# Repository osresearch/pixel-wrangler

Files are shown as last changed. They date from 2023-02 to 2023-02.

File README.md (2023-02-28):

# Pixel Wrangler: HDMI to whatever

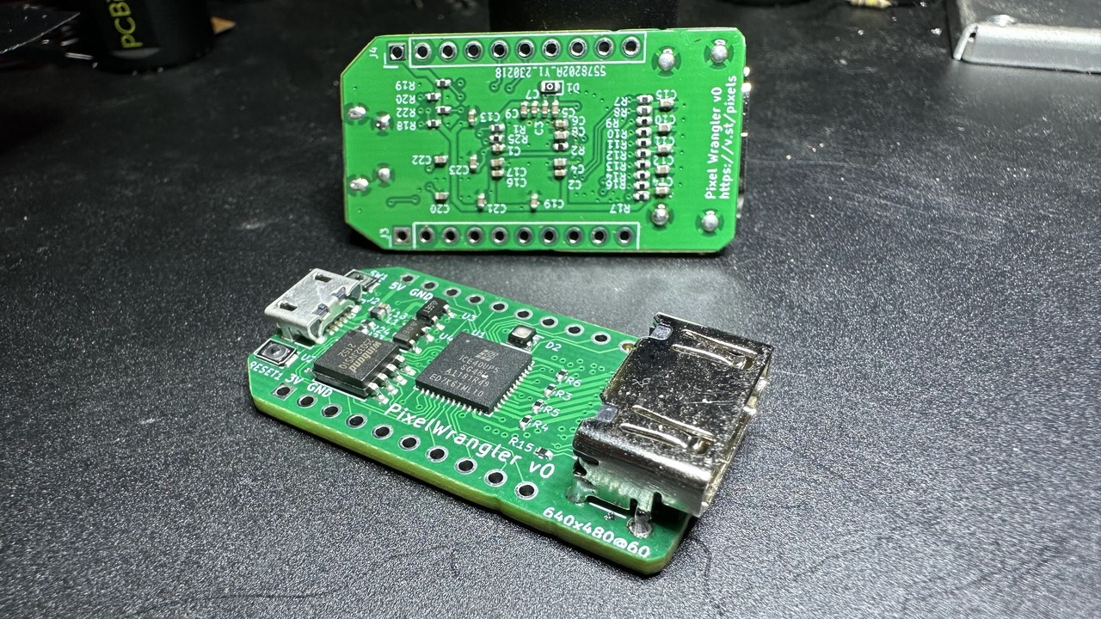
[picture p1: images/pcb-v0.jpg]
Two assembled v0 pixel wrangler boards


The Pixel Wrangler is a tool for converting HDMI video into anything else.
It uses an ice40up5k FPGA to decode the video stream and stores a section
of it in the block RAM, which can then be clocked out of the 16 GPIO pins
in any other format required.

Since the FPGA has total flexibility in how it drives the output pins
it is easily adaptable to different protocols.  Some examples that are possible:

* Classic CRT like the original Mac or Hercules monitors
* LED matrices
* Flip dots
* LED strips (ws2812 or other protocols)
* Lots of servos for "wooden mirrors"

## Does it work?

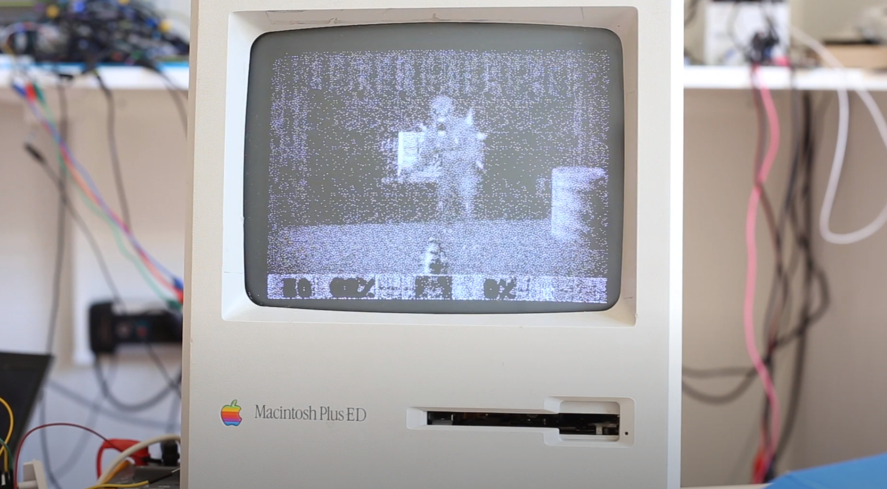
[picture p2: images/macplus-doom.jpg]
Mac Plus "running" Doom


Mostly! The EDID output is good enough to convince Linux to use it as
a normal, if low-resolution, display.  The `mac.bin` monitor mode has
"*live dithering*" to convert the color display into 1-bit, which
works well enough to [play Doom on a 9" Mac Plus](https://www.youtube.com/watch?v=UI3e4YboR_g)!

With `xrandr` it is possible to
have it use a small section of the primary monitor if you don't want a
separate head:

```
xrandr --output HDMI-2 --pos 350x100
```

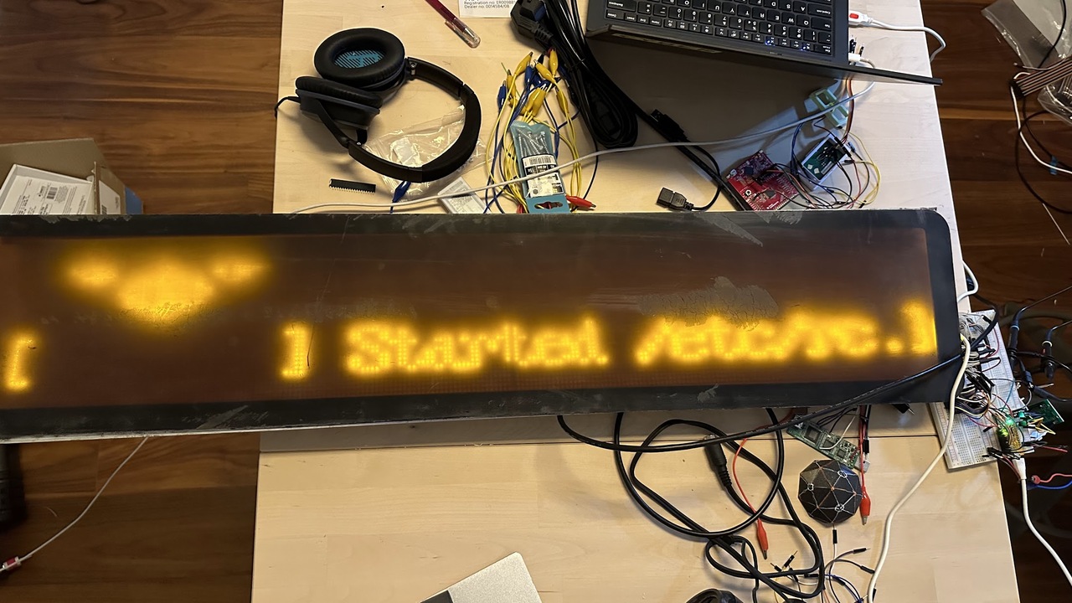
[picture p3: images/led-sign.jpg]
LED sign from a train with the Raspberry Pi boot image


There are some [problems with the v0 boards](https://github.com/osresearch/pixel-wrangler/issues/22),
one of which reqiures a bodge wire on the i2c lines.  The 5v pullups on
the source side of the HDMI i2c also might cause problems in the FPGA,
so the boards need some redesign.

The [TMDS D1 and D2 channels aren't working](https://github.com/osresearch/pixel-wrangler/issues/23),
so right now only the blue data on channel D0 is used.
This might be a clock phase issue or it might be a larger problem;
more research is needed.

The USB Micro is directly connected to the ice40up5k and the flash
can be loaded with [TinyFPGA bootloader `pixelwrangler` branch](https://github.com/osresearch/TinyFPGA-Bootloader/tree/pixelwrangler)
to allow new bit streams to be uploaded into the device.
The [`multiboot.bin`](image/multiboot.bin) is prebuilt and can
be flashed with your SPI flasher of choice and then the `bootmeta.json`
and `boardmeta.json` can be written into the flash security pages.

## PCB design

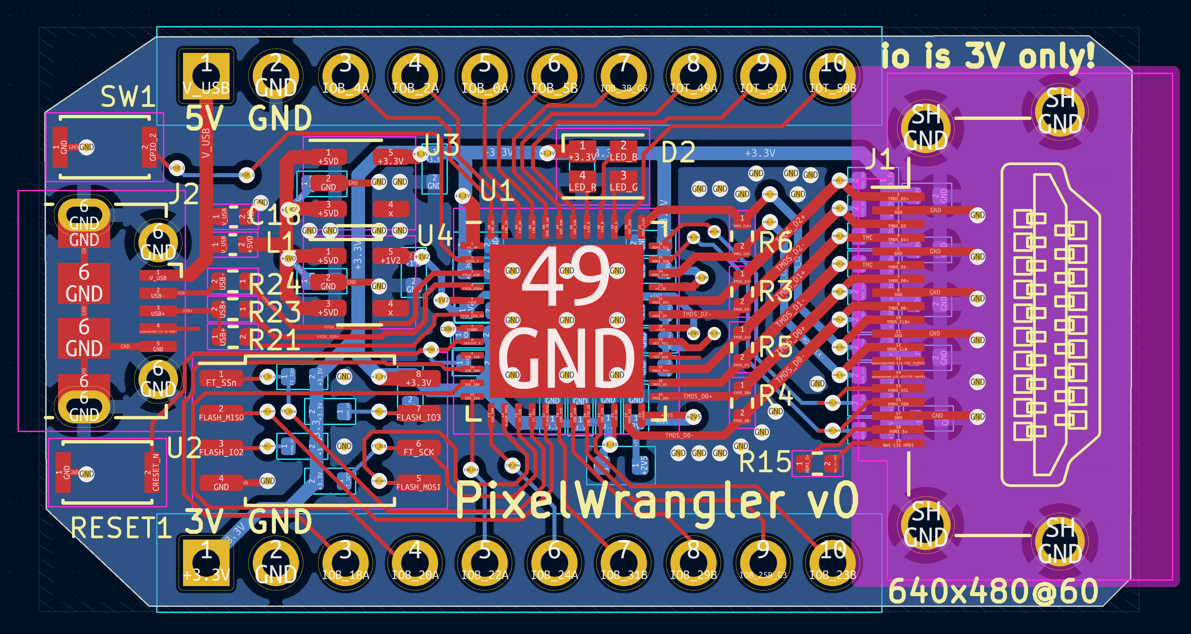
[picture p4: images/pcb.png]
Early PCB layout with air wires


[v0 Schematic](pcb/wrangler_v0.pdf) is based on the [UPduino v3.0 by tinyvision.ai](https://www.tindie.com/products/tinyvision_ai/upduino-v31-low-cost-lattice-ice40-fpga-board/),
heavily modified for this specific application.

The HDMI connector has one differential pair carrying a 25 MHz clock and three differential
pairs running at 250 MHz and carrying 10 bits per pixel.  The clock *must* connect
to the one pin on the ice40up5k that has a LVDS connection to the global clock buffer
so that the pixel clock can be quickly fanned-out to the rest of the logic that uses it.
The three data pairs are routed to the LVDS inputs; D0 and D1 are inverted so that they
don't have to cross on the PCB and must be flipped in the logic.

## Limitations

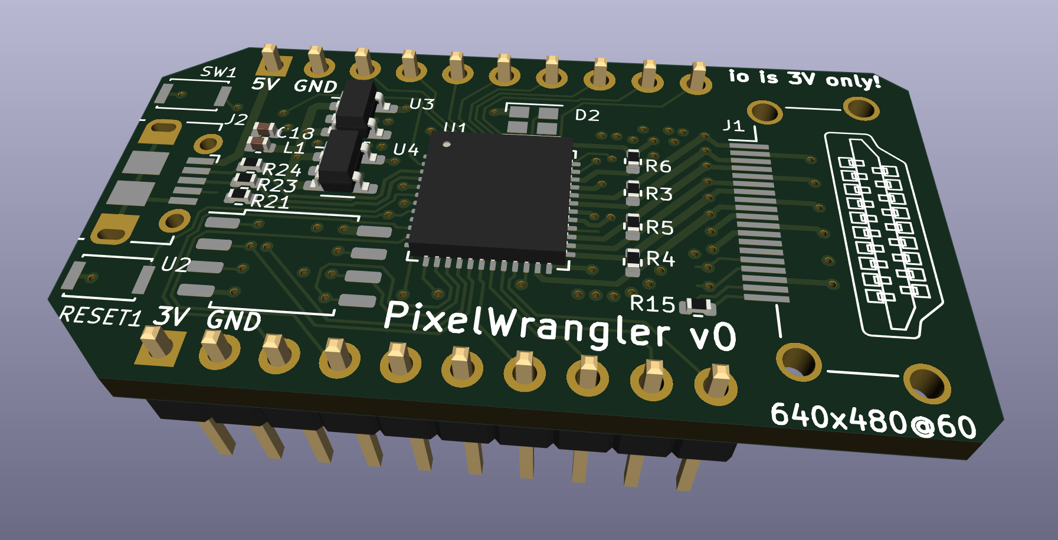
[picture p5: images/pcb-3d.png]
Rendering of the pre-production beta board


* Only "baseline video" is supported
  * 640x480 @ 60Hz
  * 25 MHz maximum pixel clock
* 1 Mib frame buffer memory in the ice40. Resolutions supported are:
  * 1024x1024x1
  * 512x512x4
  * 256x256x16
  * 256x128x24
* 3.3V IO on GPIO pins
* No protection against shorts or overcurrent. Be careful!
* Boot loader requires button press to reset
* There isn't any USB support in the bit stream tree yet.

## Dithering

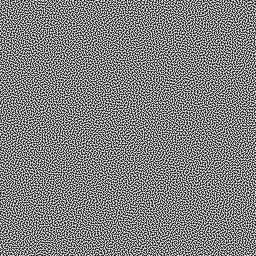
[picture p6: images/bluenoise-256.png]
256x256 Blue Noise matrix


Dithering uses Ordered Blue Noise Dithering. Pattern is from [gao-duan](https://github.com/gao-duan/BlueNoise) (MIT Licensed).
Currently limited to a 64x64 size pattern; ideally a larger RGB
image could be loaded from the SPI flash at boot time, which would
allow three channel dithering without repeating across the screen.

## Todo

* [X] Finish board design -- ordered!
* [X] EDID ROM and i2c interface
* [X] DDR on input for ~~high-res~~ inputs
* [X] Classic Mac mode -- working!
* [ ] Fix TMDS channel D1 and D2 decoding
* [ ] Documentation on writing new interfaces
* [ ] LED strip mode
* [ ] Load larger dithering pattern from flash?

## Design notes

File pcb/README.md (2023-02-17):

This is derived from the UPduino v3 board design by tinyvision-ai-inc:
https://github.com/tinyvision-ai-inc/UPduino-v3.0

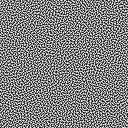
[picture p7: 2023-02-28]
images/bluenoise-128.png

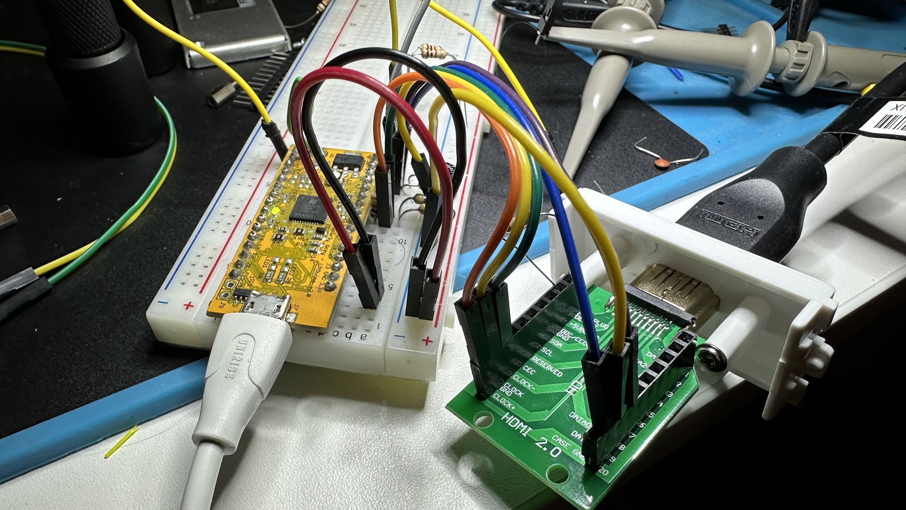
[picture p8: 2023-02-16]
images/breadboard.jpg

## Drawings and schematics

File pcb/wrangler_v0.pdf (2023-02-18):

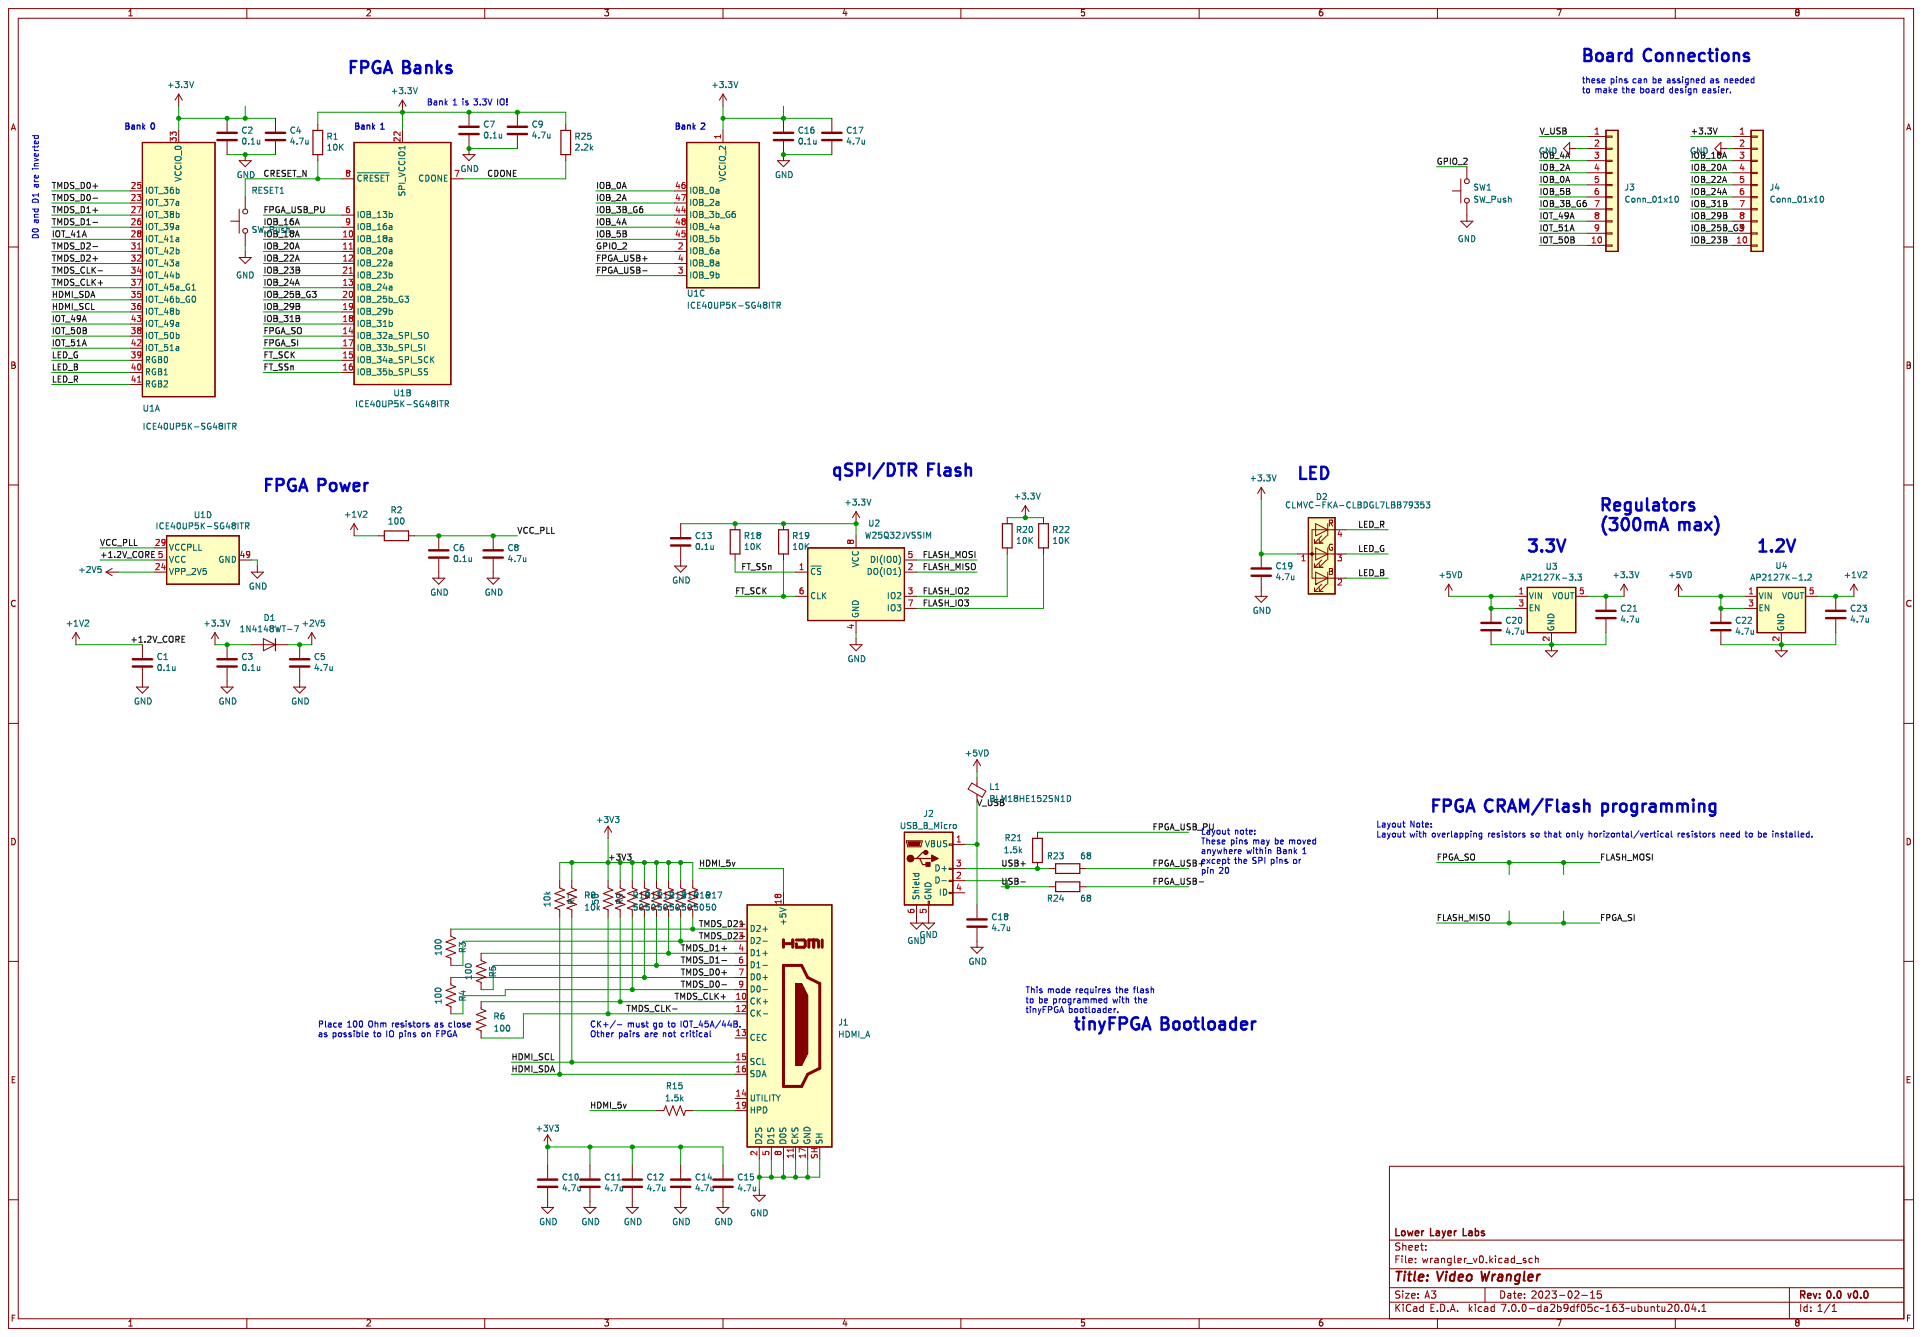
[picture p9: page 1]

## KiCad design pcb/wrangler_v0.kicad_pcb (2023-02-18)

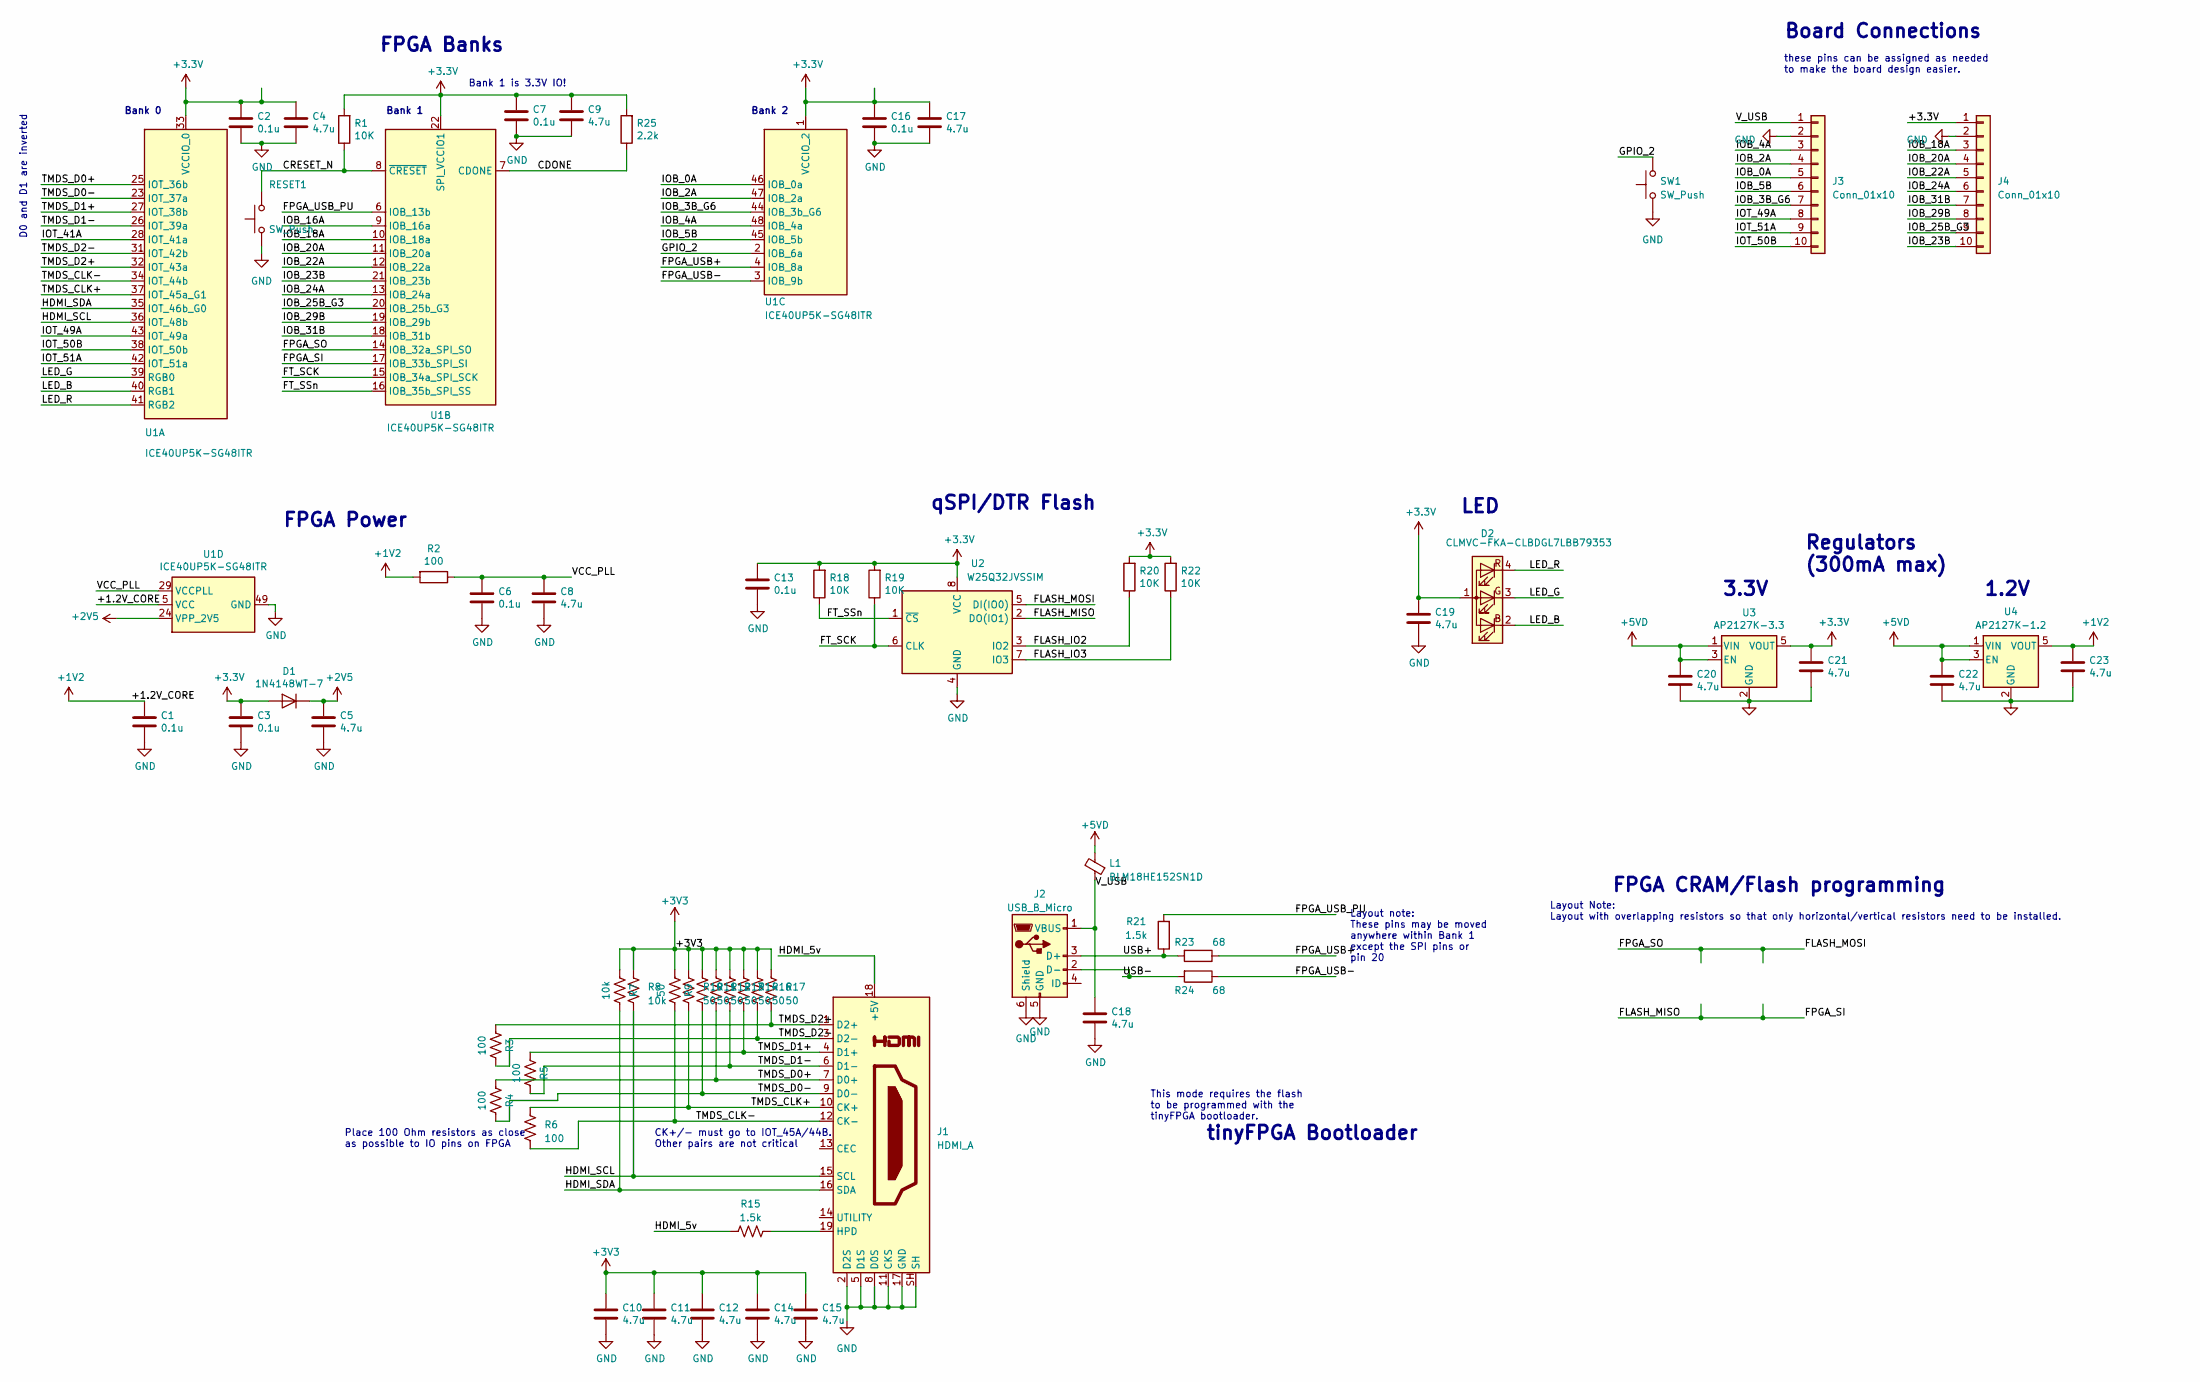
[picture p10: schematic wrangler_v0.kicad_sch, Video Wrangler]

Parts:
C1, C3, C6, C7, C13, C16: 0.1u; C_0402_1005Metric
C2: 0.1u; C_0402_1005Metric; MPN C1005X5R0J104K050BA
C4, C5, C8, C9, C10, C11, C12, C14, C15, C17, C18, C19, C20, C21, C22, C23: 4.7u; C_0402_1005Metric
D1: 1N4148WT-7; D_SOD-523
D2: CLMVC-FKA-CLBDGL7LBB79353; LED_Cree-PLCC4_2x2mm_CW
J1: HDMI_A; HDMI_A_Amphenol_10029449-x01xLF_Horizontal
J2: USB_B_Micro; USB_Micro-B_Molex-105017-0001
J3, J4: Conn_01x10; PinHeader_1x10_P2.54mm_Vertical
L1: BLM18HE152SN1D; C_0402_1005Metric
R1, R18, R19, R20, R22: 10K; R_0402_1005Metric
R2, R3, R4, R5, R6: 100; R_0402_1005Metric
R7, R8: 10k; R_0402_1005Metric
R9, R10, R11, R12, R13, R14, R16, R17: 50; R_0402_1005Metric
R15, R21: 1.5k; R_0402_1005Metric
R23, R24: 68; R_0402_1005Metric
R25: 2.2k; R_0402_1005Metric
RESET1: SW_Push; SW_SPST_CK_KXT3
SW1: SW_Push; SW_SPST_CK_KXT3
U1: ICE40UP5K-SG48ITR; QFN-48-1EP_7x7mm_P0.5mm_EP5.6x5.6mm
U2: W25Q32JVSSIM; SOIC-8_5.23x5.23mm_P1.27mm
U3: AP2127K-3.3; SOT-23-5
U4: AP2127K-1.2; SOT-23-5

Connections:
+1V2: C1.1, C23.1, R2.2, U1.5 (VCC), U1.30 (VCC), U4.5 (VOUT)
+2V5: C5.1, D1.1 (K), U1.24 (VPP_2V5)
+5VD: C20.1, C22.1, L1.2, U3.1 (VIN), U3.3 (EN), U4.1 (VIN), U4.3 (EN)
/CDONE: R25.1, U1.7 (CDONE)
/CRESET_N: R1.1, RESET1.2, U1.8 (~CRESET)
/FLASH_IO2: R20.1, U2.3 (IO2)
/FLASH_IO3: R22.1, U2.7 (IO3)
/FLASH_MISO: U1.17 (IOB_33b_SPI_SI), U2.2 (DO(IO1))
/FLASH_MOSI: U1.14 (IOB_32a_SPI_SO), U2.5 (DI(IO0))
/FPGA_USB+: R23.1, U1.4 (IOB_8a)
/FPGA_USB-: R24.1, U1.3 (IOB_9b)
/FPGA_USB_PU: R21.2, U1.6 (IOB_13b)
/FT_SCK: R19.1, U1.15 (IOB_34a_SPI_SCK), U2.6 (CLK)
/FT_SSn: R18.1, U1.16 (IOB_35b_SPI_SS), U2.1 (~CS)
/GPIO_2: SW1.2, U1.2 (IOB_6a)
/HDMI_5v: J1.18 (+5V), R15.1
/HDMI_SCL: J1.15 (SCL), R8.2, U1.36 (IOT_48b)
/HDMI_SDA: J1.16 (SDA), R7.2, U1.35 (IOT_46b_G0)
/IOB_0A: J3.5, U1.46 (IOB_0a)
/IOB_2A: J3.4, U1.47 (IOB_2a)
/IOB_3B_G6: J3.7, U1.44 (IOB_3b_G6)
/IOB_4A: J3.3, U1.48 (IOB_4a)
/IOB_5B: J3.6, U1.45 (IOB_5b)
/IOB_16A: U1.9 (IOB_16a)
/IOB_18A: J4.3, U1.10 (IOB_18a)
/IOB_20A: J4.4, U1.11 (IOB_20a)
/IOB_22A: J4.5, U1.12 (IOB_22a)
/IOB_23B: J4.10, U1.21 (IOB_23b)
/IOB_24A: J4.6, U1.13 (IOB_24a)
/IOB_25B_G3: J4.9, U1.20 (IOB_25b_G3)
/IOB_29B: J4.8, U1.19 (IOB_29b)
/IOB_31B: J4.7, U1.18 (IOB_31b)
/IOT_41A: U1.28 (IOT_41a)
/IOT_49A: J3.8, U1.43 (IOT_49a)
/IOT_50B: J3.10, U1.38 (IOT_50b)
/IOT_51A: J3.9, U1.42 (IOT_51a)
/LED_B: D2.2 (RK), U1.40 (RGB1)
/LED_G: D2.3 (GK), U1.39 (RGB0)
/LED_R: D2.4 (BK), U1.41 (RGB2)
/TMDS_CLK+: J1.10 (CK+), R6.1, R10.2, U1.37 (IOT_45a_G1)
/TMDS_CLK-: J1.12 (CK-), R6.2, R9.2, U1.34 (IOT_44b)
/TMDS_D0+: J1.7 (D0+), R4.1, R12.2, U1.25 (IOT_36b)
/TMDS_D0-: J1.9 (D0-), R4.2, R11.2, U1.23 (IOT_37a)
/TMDS_D1+: J1.4 (D1+), R5.1, R14.2, U1.27 (IOT_38b)
/TMDS_D1-: J1.6 (D1-), R5.2, R13.2, U1.26 (IOT_39a)
/TMDS_D2+: J1.1 (D2+), R3.1, R17.2, U1.32 (IOT_43a)
/TMDS_D2-: J1.3 (D2-), R3.2, R16.2, U1.31 (IOT_42b)
/USB+: J2.3 (D+), R21.1, R23.2
/USB-: J2.2 (D-), R24.2
/VCC_PLL: C6.1, C8.1, R2.1, U1.29 (VCCPLL)
/V_USB: C18.1, J2.1 (VBUS), J3.1, L1.1
GND: C1.2, C2.2, C3.2, C4.2, C5.2, C6.2, C7.2, C8.2, C9.2, C10.2, C11.2, C12.2, C13.2, C14.2, C15.2, C16.2, C17.2, C18.2, C19.2, C20.2, C21.2, C22.2, C23.2, J1.2 (D2S), J1.5 (D1S), J1.8 (D0S), J1.11 (CKS), J1.17 (GND), J1.SH, J2.5 (GND), J2.6 (Shield), J3.2, J4.2, RESET1.1, SW1.1, U1.49 (GND), U2.4 (GND), U3.2 (GND), U4.2 (GND)
unnamed: J1.19 (HPD), R15.2

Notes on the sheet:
Bank 1
Bank 1 is 3.3V IO!
Layout note: These pins may be moved anywhere within Bank 1 except the SPI pins or pin 20
tinyFPGA Bootloader
LED
FPGA Power
This mode requires the flash to be programmed with the tinyFPGA bootloader.
CK+/- must go to IOT_45A/44B. Other pairs are not critical
Layout Note: Layout with overlapping resistors so that only horizontal/vertical resistors need to be installed.
3.3V
D0 and D1 are inverted
Place 100 Ohm resistors as close as possible to IO pins on FPGA
Bank 0
Board Connections
1.2V
Bank 2
qSPI/DTR Flash
FPGA Banks
Regulators (300mA max)
these pins can be assigned as needed to make the board design easier.
FPGA CRAM/Flash programming

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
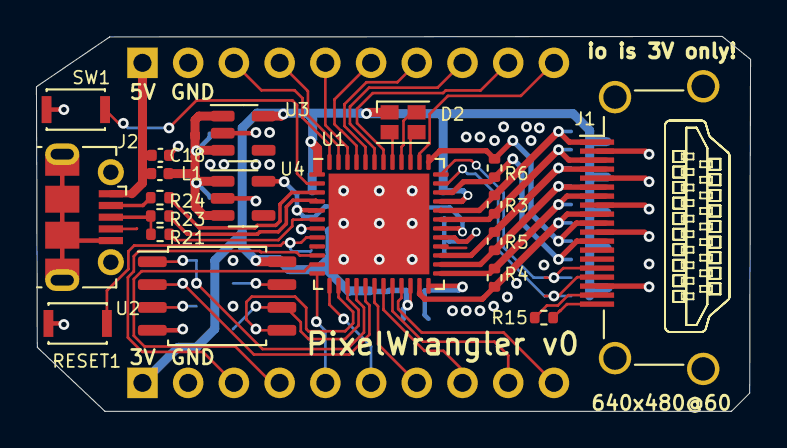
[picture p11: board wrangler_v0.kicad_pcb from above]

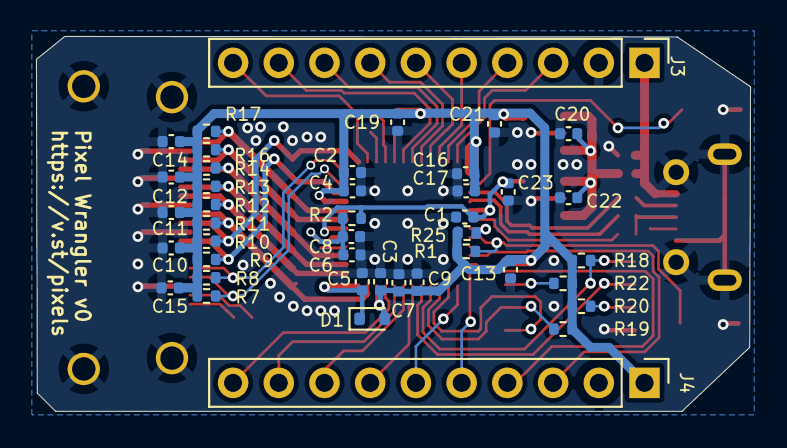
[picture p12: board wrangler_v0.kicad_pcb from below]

Board: 4 copper layers, 39.7 x 20.8 mm, 61 parts (42 on the bottom side), 52 nets.

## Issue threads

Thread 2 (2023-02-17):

CDONE needs to be tied high and SPI flash boot mode

osresearch, 2023-02-17:
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

According to the ice40 programming guide `CDONE` has to be tied high with a 2.7K resistor, and `SPI_SS_B` should have a 10K pullup.

osresearch, 2023-02-17:
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

* FPGA is in SPI controller mode
* `SPI_SO` is output from the FPGA. connects to flash MOSI
* `SPI_SI` is input to the FPGA, connects to flash MISO
* `SPI_SS_B` has 10k pullup

osresearch, 2023-02-18:
Fixed in v0 tag prior to ordering.

Closed 2023-02-18.

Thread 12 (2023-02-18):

usb bootloader

osresearch, 2023-02-18:
The boards don't have a FTDI chip, so it is necessary to have a bootloader.  TinyFPGA has one, FOMU has a DFU based one.

osresearch, 2023-02-18:
Hopefully it works without a crystal.  if not we can just route normal serial over the USB micro in a total non-standard sort of connector.

osresearch, 2023-03-01:
tinyfpga bootloader works as part of v0 fixes merge.  pre-built binary checked in, pull request opened for tinyfpga tree.

Closed 2023-03-01.

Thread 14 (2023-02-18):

tmds decoder needs invert option

osresearch, 2023-02-18:
Since the v0 board inverts some of the TMDS pairs to avoid crossings of traces on the PCB, the `tmds_shiftregister` or `tmds_decoder` needs an invert parameter.

osresearch, 2023-03-01:
Done as part of v0 fixes merge

Closed 2023-03-01.

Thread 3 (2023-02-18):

EDID emulator

osresearch, 2023-02-18:
The EDID format is awful, but we need to support it anyway...

Adafruit has some example EDID roms that do 800x600 and other formats; maybe we can hack one of those to implement the 640x480@60 timings.

ladyada, 2023-02-18:
i have lost significant life to EDID hacking - just FYI...some OS's 'cache' EDIDs: linux does, windows doesn't seem to. so if you're wondering why it doesn't reload, thats why. there's lots of EDID editors/generateors/extractors tools used in the AV world that are downloadable for free (google for edid editor)

osresearch, 2023-02-18:
Thanks for the advice!

I'm surprised there isn't any online editor, only only decoders.  I can't get the deltacast one to run under wine, so i'll need to spinup a real windows vm to try it out.

osresearch, 2023-02-19:
Hacking in a soft i2c core since I can't figure out Lattice's i2c device and it seems that icestorm devs don't recommend it anyway...

```
[3555446.841541] i915 0000:00:02.0: HDMI-A-2: EDID is invalid:
[3555446.841543]        [00] BAD  00 ff ff ff ff ff ff 00 5a 74 01 00 57 04 00 00
[3555446.841544]        [00] BAD  0a 21 01 04 a2 00 00 78 00 00 00 00 00 00 00 00
[3555446.841544]        [00] BAD  00 00 00 20 00 00 31 40 01 00 01 00 01 00 01 00
[3555446.841545]        [00] BAD  01 00 01 00 01 00 d5 09 80 a0 20 c1 ff ff ff ff
[3555446.841545]        [00] BAD  ff ff ff ff ff ff ff ff ff ff ff ff ff ff ff ff
[3555446.841545]        [00] BAD  ff ff ff ff ff ff ff ff ff ff ff ff ff ff ff ff
[3555446.841546]        [00] BAD  ff ff ff ff ff ff ff ff ff ff ff ff ff ff ff ff
[3555446.841546]        [00] BAD  ff ff ff ff ff ff ff ff ff ff ff ff ff ff ff ff
[3555451.384838] i2c i2c-1: sendbytes: NAK bailout.
[3555455.772344] i2c i2c-1: sendbytes: NAK bailout.
```

osresearch, 2023-02-19:
for future reference, i2c eeprom address is 0x50.  getting closer!
```
sudo get-edid -i -b 1 | parse-edid
1
This is read-edid version 3.0.2. Prepare for some fun.
Attempting to use i2c interface
Only trying 1 as per your request.
256-byte EDID successfully retrieved from i2c bus 1
Looks like i2c was successful. Have a good day.
WARNING: Checksum failed
Trying to continue...
Section "Monitor"
	Identifier "Pixe���angler"
	ModelName "Pixe���angler"
	VendorName "VST"
	# Monitor Manufactured week 10 of 2023
	# EDID version 1.255
	# Digital Display
	# Display Physical Size not given. Normal for projectors.
	Gamma 2.20
	Option "DPMS" "false"
	#Not giving standard mode: 640x480, 60Hz
	#Not giving standard mode: 256x160, 60Hz
	#Not giving standard mode: 256x160, 60Hz
	#Not giving standard mode: 256x160, 60Hz
	#Not giving standard mode: 256x160, 60Hz
	#Not giving standard mode: 256x160, 60Hz
	#Not giving standard mode: 256x160, 60Hz
	#Not giving standard mode: 256x160, 60Hz
EndSection
```

osresearch, 2023-02-19:
oh no, it looks like to be HDMI compliant the i2c lines are supposed to be pulled up to 5V, not 3.3V.  the ice40up5k isn't 5v tolerant, so that would require a bidirectional level shifter on the SDA line (the SCL is input only).  this would complicate things.

osresearch, 2023-02-20:
Hurrah! the i2c device now properly implements the repeated START state and delivers an error free EDID, although x isn't swithcing to it for some reason.

https://github.com/osresearch/pixel-wrangler/commit/0d43c9e86c644c38e9c9a46d856a12ce9686b799

osresearch, 2023-02-20:
Linux (x86) can be forced to use the HDMI even though it doesn't like the EDID:

```
echo on-digital | sudo tee /sys/class/drm/card0-HDMI-A-2/status
xrandr --output HDMI-2 --mode 640x480
```

Hot plug isn't doing the right thing, although if you mess with the pullup resistor it can cause the kernel to decide that there is a drm interrupt storm.

The adafruit 800x480 EDID almost works, although we can't handled the 32 MHz pixel clock yet.

osresearch, 2023-02-20:
I think the EDID emulation works well enough now:
```
sudo get-edid  -b 1 | parse-edid
1
This is read-edid version 3.0.2. Prepare for some fun.
Attempting to use i2c interface
Only trying 1 as per your request.
256-byte EDID successfully retrieved from i2c bus 1
Looks like i2c was successful. Have a good day.
Checksum Correct

Section "Monitor"
	Identifier "PixelWrangler"
	ModelName "PixelWrangler"
	VendorName "PXL"
	# Monitor Model Year: 2023
	# EDID version 1.4
	# Digital Display
	DisplaySize 640 480
	Gamma 2.20
	Option "DPMS" "false"
	Modeline 	"Mode 0" 25.17 640 656 752 800 480 490 492 525 -hsync -vsync
EndSection
```

The problem appears to be with hotplug or with X rejecting the 640x480 display parameters?  Let's move that to a new issue.

Closed 2023-02-20.

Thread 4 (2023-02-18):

DDR phase tracking is not good

osresearch, 2023-02-18:
Sometimes it doesn't seem to lock on, ever?

Maybe needs to track both positive and negative possibilities?

Phase counter needs to go from 0 to 5, not up to 10.

Closed 2023-03-23.

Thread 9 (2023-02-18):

LED is too bright

osresearch, 2023-02-18:
the ice40 rgb driver has current control; turn it down!

osresearch, 2023-03-01:
rgb driver and pwm with exponential scaling merged as part of v0

Closed 2023-03-01.

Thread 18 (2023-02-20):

tmds sync requires reset to resync

osresearch, 2023-02-20:
I think #6 is fixed with the DDR mode, but there is still a problem that decoder doesn't resync with the stream after a hotplug. it requires the full fpga to reset to come back to working.

osresearch, 2023-02-20:
Adding an async `hdmi_reset` signal seems to have worked.  the blue LED shows when it is being asserted, and it is very bright....

Closed 2023-02-20.

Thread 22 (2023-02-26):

v0 board issues

osresearch, 2023-02-26:
* [ ] L1 is too close to cap on the top
* [ ] Reset and SW1 should be brought to the headers
* [ ] Two IOs are not routed out
* [ ] USB footprint isn't quite right
* [ ] USB resistors are on the top; move to bottom?
* [ ] Add a clock?
* [ ] Reduce size of paste window under ice40
* [ ] Make sure to order ENIG plating!
* [ ] 1.2mm thick PCB
* [ ] Smaller stencil size

cibomahto, 2023-02-26:
My suggestions:
* Change button type to 'TS-1185-C-A-A': https://www.lcsc.com/product-detail/Others_XKB-TS-1185-C-A-A_C318896.html (slightly larger but more robust/very common)
* Change USB type to 'MICRO XNJ ZB' https://www.lcsc.com/product-detail/USB-Connectors_SHOU-HAN-MICRO-XNJ-ZB_C668587.html (this works with the current footprint?)
* Suggest 2520 oscillator package size, for example: https://www.lcsc.com/product-detail/Oscillators_Yangxing-Tech-OT252012MJBA4SL_C669073.html
* Leave USB resistors on top side (keep USB lines on a single plane to avoid discontinuities)
* Consider if the other end of the I2C pins are being pulled up to 5V, which would make a voltage conflict.

osresearch, 2023-02-26:
Thanks for the suggestions!

Software patches are being developed in https://github.com/osresearch/pixel-wrangler/tree/v0-fixes

osresearch, 2023-02-27:
For the i2c pullups, perhaps using a device-side version of the [TPD12S016 "HDMI Companion chip"](https://nl.mouser.com/ProductDetail/Texas-Instruments/TPD12S016RKTR) would be a good idea.  It adds ESD protection on all eight differential pairs, i2c level shifting, etc.

osresearch, 2023-02-27:
After soldering a jumper from the SDA pullup resistor to GPIO 0 7, the i2c works and the laptop negotiates with the display.  All three channel decode works.  Green is inverted on schematic, but doesn't get inverted in the verilog?  Something seems wrong with that.

osresearch, 2023-12-07:
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

I forgot to check all the replies to this issue and forgot to change the switch or USB footprints.  I did fix the i2c connections and moved everything to one side for easier manufacturing.

Aisler is doing the prototype and they only have thick PCBs.

osresearch, 2024-02-10:
And some v2 board issues:

The biggest:

* The v2 boards won't sync up their PLL, so they never get the video (maybe the througholes are a bad idea)
* Maybe this is a bad idea and it should just use an HDMI chip

And some other ones:

* Not having an oscillator means that free running video outputs have some shimmer (on v0 and v2).
* Buttons are still too hard to press
* USB micro rips off sometimes
* Initial program load is a problem; have to figure out how to make it work on populated boards
* Boot loader doesn't time out and start video automatically
* Boot loader metadata isn't populated correctly

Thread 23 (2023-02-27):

TMDS D1 and D2 phases

osresearch, 2023-02-27:
Are we getting 0-255 or 16-235?

osresearch, 2023-02-27:
Blue gradient:
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

Red gradient:
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

Green gradient:
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

It's not a full RGB issue, it appears to be a TMDS phase issue.  The blue channel on D0 can synchronize on the vsync with all of its 01 transitions, but the D1 and D2 don't have that option. The 8b10b encoding for 0x00 and 0xFF have very few transitions, so out of phase means that the decoder mostly gets ok data for full on and full off.  But if D1 and D2 are on different phases, they will have garbage.

osresearch, 2023-02-28:
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

the control bits are the same on each channel:

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

and the patterns are
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

osresearch, 2023-02-28:
one idea is to dump the incoming bit stream from the d1 channel into DP block RAM and then have the uart dump it out.

this would require a serial port on the extra gpio pins.

osresearch, 2023-03-01:
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

omg I think I see the problem.  need to use DDR or non-DDR for all the tmds shift registers

Closed 2023-03-01.

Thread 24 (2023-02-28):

mac has off-by-one error in last line?

osresearch, 2023-02-28:
the framebuffer has garbage on the very last line, probably due to a > versus >= somewhere

osresearch, 2023-03-23:
Fixed in the glitch branch

Closed 2023-03-23.

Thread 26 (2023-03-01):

Sync to HDMI vsync

osresearch, 2023-03-01:
For better filming it might be useful to start drawing the frame when the hdmi vsync fires.  currently the mac output draws at a constant speed, but it could instead (when HDMI is locked) use the vsync signal pulse instead.

The 125 MHz clock could also be divided by 8 for a 15.625 MHz clock that would be a better match (?) for the 15.71 that the schematic has for the Mac Plus.  This might expand the screen out sideways slightly.

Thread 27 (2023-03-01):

i2c needs 5v protection

osresearch, 2023-03-01:
as part of the v0 board issues (#22), the i2c line needs a level shifter.  It is weakly pulled to 5v on the HDMI source side, which could damage the FPGA that is pulling it high to 3.3v.

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

the [TI TPD12S016 "HDMI Companion Chip"](https://www.ti.com/product/TPD12S016) is a single chip device that also adds ESD filtering so it might be worth spending the $0.80 each to add to the BOM. As a plus, the pinout matches the HDMI port, so hopefully it is a "drop in" with a slight tweak to the board size.

osresearch, 2023-03-01:
although this comment says it can't be used as an HDM sink due to pullup resistors, although they don't provide any altneratives. https://e2e.ti.com/support/interface-group/interface/f/interface-forum/458493/tpd5s116-used-as-hdmi-sink

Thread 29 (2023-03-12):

Availability of the pixel-wrangler hardware

stitch, 2023-03-12:
Hi Trammell,

I'm super impressed with this project. I'd like to use it as an easy way to drive a pixel display in my cyber coin pusher at the end of the year ccc conference. Do you plan this hardware to be going into production sometime?

https://twitter.com/TheCyberPusher

Regards,
Elger / Stitch

osresearch, 2023-03-12:
Production plans are uncertain, although I have an unpopulated v0 board if you want to hack on it.  It works, although there are some issues remaining with the HDMI decode. Some place-and-routes are totally stable and produce beautiful glitch free framebuffer imgaes, while others are nothing but static.  I've been chasing this for the past two weeks -- we're pushing the limits of the ice40 fabric -- and all of the demo videos are from the lucky ones that worked well.

So if you have some tolerance for instability during testing and finding a bitstream that gives you a solid decoding, you're welcome to one of the boards!

osresearch, 2023-03-23:
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

The glitch branch is looking much better, so I'm optimistic that we have the timing issues sorted.  Any chance you'll be at the hackaday berlin meetup this weekend? I have a self-contained demo board to show off.

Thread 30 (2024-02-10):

Document Mac setup without fpga

osresearch, 2024-02-10:
A very cost-optimized version can be built without the FPGA using only the Pi's DPI and an inverter.

Pinout is https://github.com/osresearch/pixel-wrangler/issues/20#issuecomment-1441602449

osresearch, 2024-02-10:
Pi `boot.config`
```
dtoverlay=dpi18
dpi_output_format=0x76017

# at 19.2 Mhz bit clock, we need 882 pixels (720*19.2/15.666)
dpi_timings=630 0 30 200 0   342 0 1 18 9  0 0 0 60 0  19200000 1

dpi_group=2
dpi_mode=87
enable_dpi_lcd=1
display_default_lcd=1

# turn off peripherals that would conflict
# also run:
# sudo systemctl disable hciuart
# sudo systemctl disable bluealsa.service
# sudo systemctl disable bluetooth.service

dtparam=i2c_arm=off
dtparam=spi=off
dtoverlay=disable-bt

# Do not automatically load overlays for detected DSI displays
display_auto_detect=0

# Enable DRM VC4 V3D driver
max_framebuffers=2

# Disable compensation for displays with overscan
disable_overscan=1

```

osresearch, 2024-02-10:
Pi pins are:

3: vsync (60Hz)
5: hsync (22.3Khz)
13: reg 7 (needs to be inverted)

Mac pins are:
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

1 White: Video
3 Orange: Hsync
5 Green: Vsync
7 Purple: Ground

osresearch, 2024-02-10:
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

Pi in various DPI modes

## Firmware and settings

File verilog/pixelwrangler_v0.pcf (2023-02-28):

# The LED pins are using the current controlled outputs
# and are negative logic (write a 0 to turn on).
set_io -nowarn led_r	41
set_io -nowarn led_g	39
set_io -nowarn led_b	40

set_io -nowarn spi_cs 16 # Drive high to ensure that the SPI flash is disabled
set_io -nowarn spi_sck 15
set_io -nowarn spi_mosi 14
set_io -nowarn spi_msio 17

set_io -nowarn pin_usbp 4 # IOB_8A
set_io -nowarn pin_usbn 3 # IOB_9B
set_io -nowarn pin_usb_pu 6 # IOB_13B

set_io -nowarn sw1 2 # IOB_6A

# HDMI input
set_io -nowarn tmds_d0p 25 # IOT_36B; needs inversion
set_io -nowarn tmds_d0n 23 # IOT_37A
set_io -nowarn tmds_d1p 27 # IOT_38B; needs inversion
set_io -nowarn tmds_d1n 26 # IOT_39A
set_io -nowarn tmds_d2p 32 # IOT_43A
set_io -nowarn tmds_d2n 31 # IOT_42B
set_io -nowarn tmds_clkp 37 # IOT_45A_G1
set_io -nowarn tmds_clkn 34 # IOT_44b
set_io -nowarn hdmi_sda 35 # IOT_46B_G0
set_io -nowarn hdmi_scl 36 # IOT_48b

# GPIO bank 0, bottom side
set_io -nowarn gpio_0_0 10 # IOB_18A
set_io -nowarn gpio_0_1 11 # IOB_20A
set_io -nowarn gpio_0_2 12 # IOB_22A
set_io -nowarn gpio_0_3 13 # IOB_24A
set_io -nowarn gpio_0_4 18 # IOB_31B
set_io -nowarn gpio_0_5 19 # IOB_29B
set_io -nowarn gpio_0_6 20 # IOB_25B_G
set_io -nowarn gpio_0_7 21 # IOB_23B

# GPIO bank 1, top side
set_io -nowarn gpio_1_0 48 # IOB_4A
set_io -nowarn gpio_1_1 47 # IOB_2A
set_io -nowarn gpio_1_2 46 # IOB_0A
set_io -nowarn gpio_1_3 45 # IOB_5B
set_io -nowarn gpio_1_4 44 # IOB_3B_G6
set_io -nowarn gpio_1_5 43 # IOB_49A
set_io -nowarn gpio_1_6 42 # IOB_51A
set_io -nowarn gpio_1_7 38 # IOB_50B

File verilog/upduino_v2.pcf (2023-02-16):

# The LED pins are using the current controlled outputs
# and are negative logic (write a 0 to turn on).
set_io -nowarn led_r	41
set_io -nowarn led_g	39
set_io -nowarn led_b	40

# FTDI chip, which sort of works
set_io -nowarn serial_txd 14 # FPGA transmit to USB
set_io -nowarn serial_rxd 15 # FPGA receive from USB
set_io -nowarn spi_cs 16 # Drive high to ensure that the SPI flash is disabled
# set_io serial_rts_n 14  # no?
# set_io serial_dtr_n 16  # no?

# Normal GPIO pins, left side
set_io -nowarn gpio_23 23
set_io -nowarn gpio_25 25
set_io -nowarn gpio_26 26
set_io -nowarn gpio_27 27
set_io -nowarn gpio_32 32
set_io -nowarn gpio_35 35
set_io -nowarn gpio_31 31
set_io -nowarn gpio_37 37
set_io -nowarn gpio_34 34
set_io -nowarn gpio_43 43
set_io -nowarn gpio_36 36
set_io -nowarn gpio_42 42
set_io -nowarn gpio_38 38
set_io -nowarn gpio_28 28

# Normal GPIO pins, right side
set_io -nowarn gpio_12 12
set_io -nowarn gpio_21 21
set_io -nowarn gpio_13 13
set_io -nowarn gpio_19 19
set_io -nowarn gpio_18 18
set_io -nowarn gpio_11 11
set_io -nowarn gpio_9 9
set_io -nowarn gpio_6 6
set_io -nowarn gpio_44 44
set_io -nowarn gpio_4 4
set_io -nowarn gpio_3 3
set_io -nowarn gpio_48 48
set_io -nowarn gpio_45 45
set_io -nowarn gpio_47 47
set_io -nowarn gpio_46 46
set_io -nowarn gpio_2 2

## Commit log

2023-02-17 pixel wrangler v0 board (based on upduino v3 and heavily modified)
    [wrangler_v0.kicad_pcb, wrangler_v0.kicad_sch]
2023-02-17 updated with comments from revspace and matt
    [wrangler_v0.kicad_pcb]
2023-02-17 PCB and upduino link
2023-02-17 forgot the uart
2023-02-18 ignore gerber files
2023-02-18 pcb: added CDONE pullup resistor and some silkscreen tweaks
    [wrangler_v0.kicad_pcb, wrangler_v0.kicad_sch]
2023-02-18 jlpcb export parameters
    [wrangler_v0.kicad_pcb]
2023-02-18 slow down the LED matrix scanning a bit, it was causing static on the display
2023-02-20 i2c almost works?
2023-02-20 uart tx/rx with baud clock generator
2023-02-20 load the edid data and instantiate an i2c device
2023-02-20 i2c: fix block read mode address pre-increment (#17)
2023-02-20 hdmi_reset: reset the state of the tmds decoder if no valid sync signals are received (#18)
    [train.v]
2023-02-21 move pwm into separate file, use the SB_RGBA_DRV to avoid overcurrent
    [train.v]
2023-02-24 pwm: fix rgb assignment for the upduino (maybe wrong for pixelwrangler boards)
2023-02-25 working multiboot image for the pixel wrangler v0 board
2023-02-26 tinyprog boardmeta and programming tools
2023-02-28 tmds: replace block ram with just two flip flop stages
2023-02-28 top: rename sw1, enable pullups on it, allow user to reset hdmi, expose bit clock to user
    [pixelwrangler_v0.pcf]
